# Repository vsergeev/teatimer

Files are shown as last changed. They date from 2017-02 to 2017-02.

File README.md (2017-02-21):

# teatimer

A simple kitchen timer implemented in digital logic on a Lattice MachXO2 CPLD.

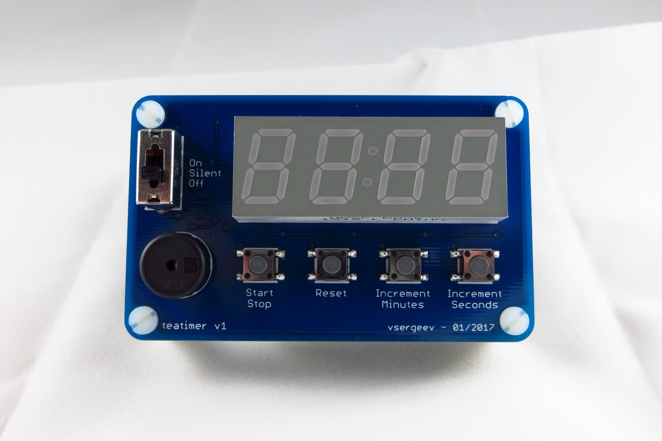
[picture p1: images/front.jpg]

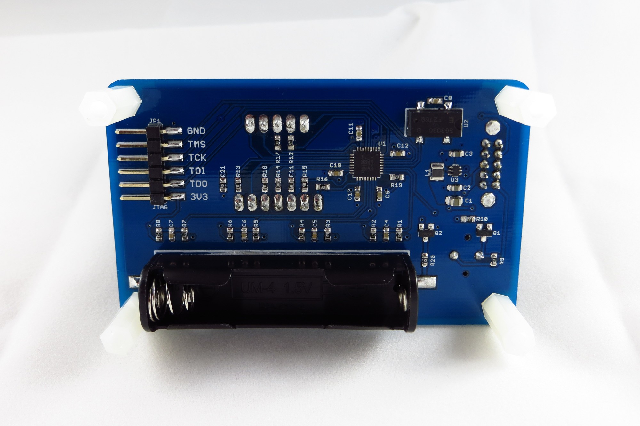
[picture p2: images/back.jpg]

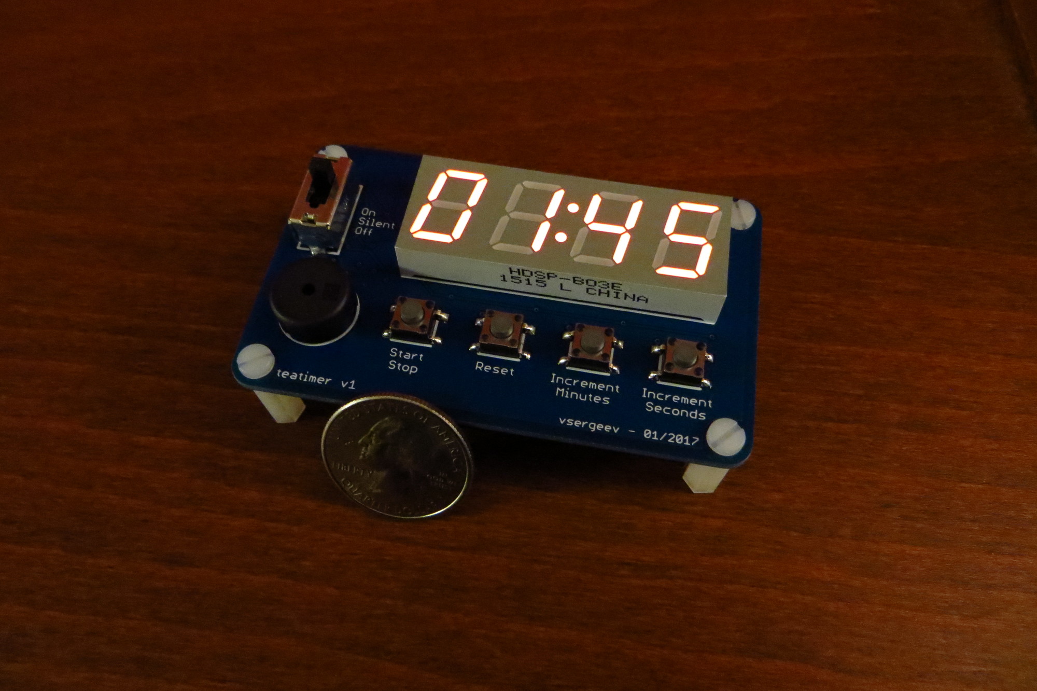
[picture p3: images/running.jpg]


(It's brighter in person.)

## Details

* Features
    * Large 7-segment display
    * Count-down/count-up timer
    * Alarm and silent modes
    * AAA battery powered
* Limitations
    * 10 hour battery life
* ICs
    * Lattice MachXO2-256 CPLD
    * SG-3030JC 32.768 kHz Oscillator
    * TLV61225 Boost Converter 1.5V -> 3.3V
* Dimensions of 80mm x 49mm
* Power consumption of ~100mA @ 1.5V (mostly from LEDs)

## Project Structure

* [`README.md`](README.md) - this README
* [`teatimer.v`](teatimer.v) - Verilog source
* [`teatimer_tb.v`](teatimer_tb.v) - Verilog test bench
* [`Makefile`](Makefile) - Makefile for simulation
* [`hw/`](hw/) - Schematic and layout
    * `teatimer.sch` - Eagle schematic
    * `teatimer.brd` - Eagle layout
    * [`teatimer-sch.png`](hw/teatimer-sch.png) - Schematic image
    * [`teatimer-brd.png`](hw/teatimer-brd.png) - Layout image
    * [`gerbers/`](hw/gerbers/) - Gerbers
* [`diamond/`](diamond/) - Lattice Diamond project
    * `teatimer.ldf` - Project file
    * `teatimer.v` - Symlinked Verilog source
    * [`teatimer.lpf`](diamond/teatimer.lpf) - Constraints
    * [`teatimer.jed`](diamond/teatimer.jed) - JEDEC bitstream
* [`misc/`](misc/) - Miscellaneous scripts

## Design Summary

The design uses 67 bits of state, 91% of the LUTs for logic, and all of the
I/O.

```
Number of registers:     67 out of   322 (21%)
   PFU registers:           63 out of   256 (25%)
   PIO registers:            4 out of    66 (6%)
Number of SLICEs:       117 out of   128 (91%)
   SLICEs as Logic/ROM:    117 out of   128 (91%)
   SLICEs as RAM:            0 out of    96 (0%)
   SLICEs as Carry:         27 out of   128 (21%)
Number of LUT4s:        232 out of   256 (91%)
   Number used as logic LUTs:        178
   Number used as distributed RAM:     0
   Number used as ripple logic:       54
   Number used as shift registers:     0
Number of PIO sites used: 18 + 4(JTAG) out of 22 (100%)
Number of block RAMs:  0 out of 0
Number of GSRs:  1 out of 1 (100%)
```

## Datasheets

* U1, Lattice MachXO2 CPLD, LCMXO2-256HC-4SG32C - [family datasheet](http://www.latticesemi.com/~/media/LatticeSemi/Documents/DataSheets/MachXO23/MachXO2FamilyDataSheet.pdf)
* U2, 32.768 kHz Oscillator, SG-3030JC32.7680KB:ROHS - [datasheet](https://support.epson.biz/td/api/doc_check.php?dl=brief_SG-3040JC)
* U3, Boost Converter, TLV61225DCKR - [datasheet](http://www.ti.com/lit/ds/symlink/tlv61225.pdf)
* DISP1, 7-segment Display, HDSP-B03E - [datasheet](https://docs.broadcom.com/docs/AV02-0568EN)
* SP1, 4kHz Buzzer, PKM13EPYH4000-A0 - [datasheet](http://search.murata.co.jp/Ceramy/image/img/w_hinm/S0040E.pdf)

## Schematic

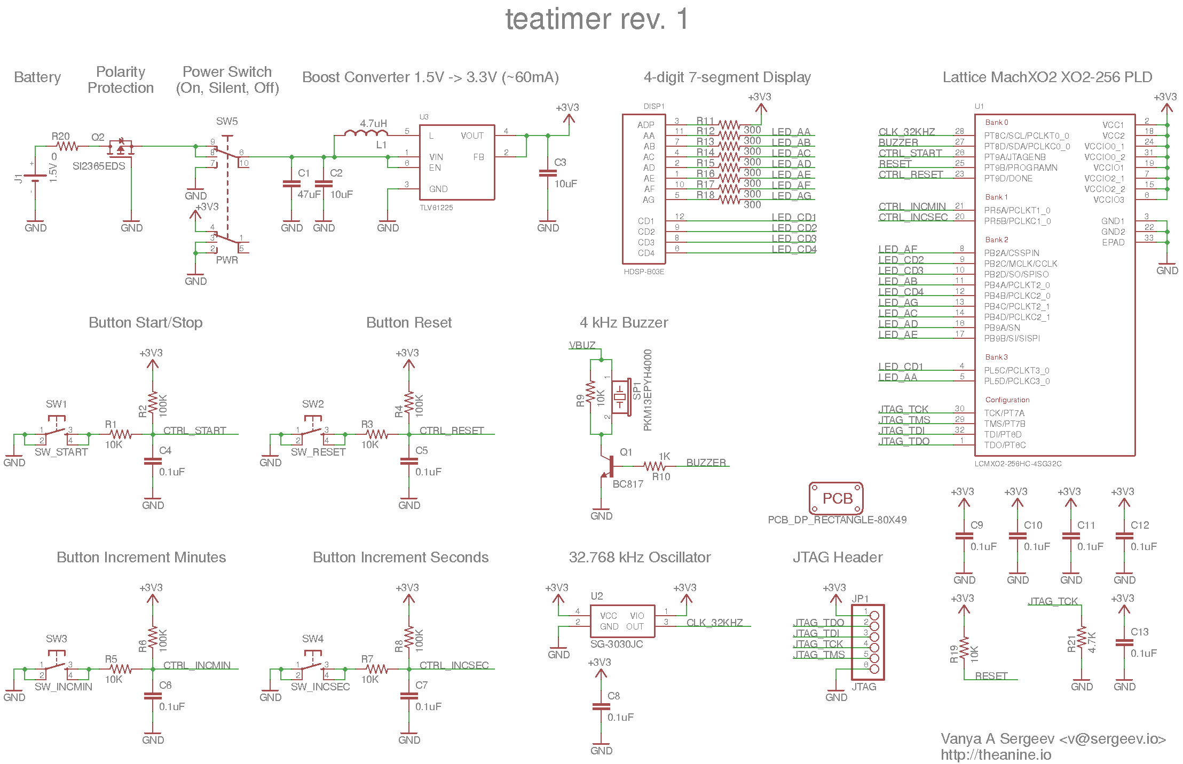
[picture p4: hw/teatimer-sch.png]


## Layout

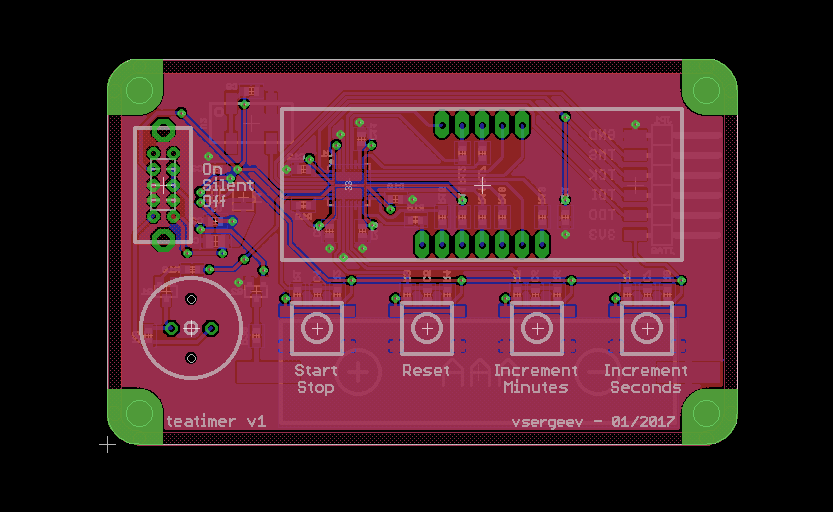
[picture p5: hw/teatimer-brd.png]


## Bill of Materials

| Qty | Part | Refdes | Digi-key Part Number | Total Price |
|:----|:---|:---|:---|:---|
| 1 | Lattice MachXO2-256 CPLD  | U1 | 220-2636-ND | 2.830 |
| 1 | Oscillator 32.768kHz | U2 | SG-3030JC32.7680KB:ROHS-ND | 1.398 |
| 1 | TLV61225 Boost Converter  | U3 | 296-36756-1-ND | 0.775 |
| 1 | NPN BJT (Buzzer Driver) | Q1 | BC817-40LT1GOSCT-ND | 0.103 |
| 1 | PMOS FET (Polarity Prot.) | Q2 | SI2365EDS-T1-GE3CT-ND | 0.297 |
| 4 | Tactile Switch (Buttons)  | SW1-SW4 | CKN9085CT-ND | 0.776 |
| 1 | Slide Switch (Power) | SW5 | CKN9558-ND | 0.648 |
| 1 | 7-segment LED Display | DISP1 | 516-2745-ND | 2.821 |
| 1 | Buzzer 4kHz | SP1 | 490-4698-ND | 0.499 |
| 1 | Battery Connector AAA | J1 | 36-2466-ND | 0.928 |
| 1 | SMD Header 1x6 | JP1 | 952-3235-ND | 0.711 |
| 1 | Inductor 4.7uH | L1 | 1276-6213-1-ND | 0.153 |
| 1 | Capacitor 47uF 0603 | C1 | 311-1897-1-ND | 0.322 |
| 2 | Capacitor 10uF 0603 | C2,C3 | 587-3258-1-ND | 0.238 |
| 10  | Capacitor 0.1uF 0603 | C4-C13 | 1276-1005-1-ND | 0.073 |
| 6 | Resistor 10K 0603 | R1,R3,R5,R7,R9,R19 | 311-10KGRCT-ND | 0.033 |
| 4 | Resistor 100K 0603 | R2,R4,R6,R8 | 311-100KGRCT-ND | 0.029 |
| 1 | Resistor 1K 0603 | R10 | 311-1.0KGRCT-ND | 0.010 |
| 1 | Resistor 4.7K 0603 | R21 | 311-4.7KGRCT-ND | 0.010 |
| 1 | Resistor 0.0 0603 | R20 | 311-0.0GRCT-ND | 0.010 |
| 8 | Resistor 300 0603 | R11-R18 | 311-300GRCT-ND | 0.044 |
| 4 | Standoffs M3 16mm Nylon | - | 952-2188-ND | 1.504 |
| 4 | Screws M3 Nylon | - | 36-29341-ND | 0.748 |
| 1 | PCB Lead-free, Shipped | - | - | 3.240 |
| | **Total per unit** | | | 18.20 |

Price breaks based on quantities to build 10 units. All prices in US dollars.

## Known Issues

* Silent mode is not 100% silent (design oversight)
* Limited battery life (~10 hours)

## Hardware Change Log

* v1 - 01/30/2017
    * Initial release

## RTL Change Log

* v0.1.0 - 01/30/2017
    * Initial release

## License

teatimer is [CC-BY-4.0](https://creativecommons.org/licenses/by/4.0/) licensed. See the included [LICENSE](LICENSE) file.

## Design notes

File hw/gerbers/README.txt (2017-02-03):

teatimer.cmp    - Top copper
teatimer.sol    - Bottom copper
teatimer.stc    - Top soldermask
teatimer.sts    - Bottom soldermask
teatimer.plc    - Top silkscreen
teatimer.pls    - Bottom silkscreen
teatimer.drd    - NC drill

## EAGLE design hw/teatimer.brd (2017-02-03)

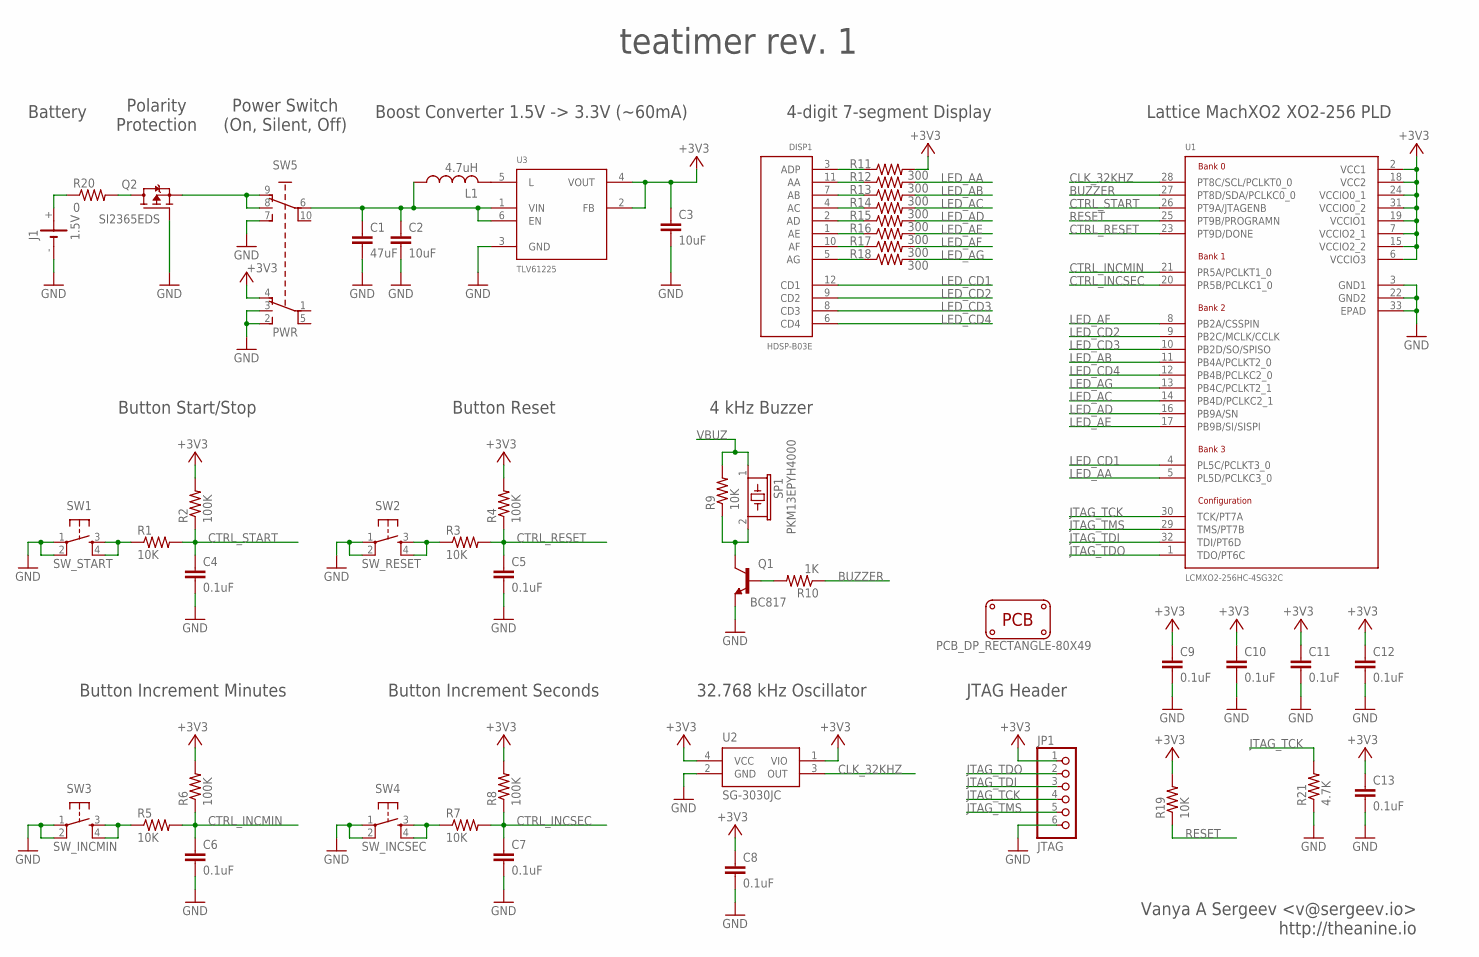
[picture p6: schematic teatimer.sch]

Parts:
C1: 47uF; C0805
C2, C3: 10uF; C0603
C4, C5, C6, C7, C8, C9, C10, C11, C12, C13: 0.1uF; C0603
DISP1: HDSP-B03E; HDSP-B0XE
J1: 1.5V; AAA-2466
JP1: JTAG; 1X06/90-SMD
L1: 4.7uH; L2520
PCB1: PCB_DP_RECTANGLE-80X49; DP8049_V1
Q1: BC817; SOT23-BEC
Q2: SI2365EDS; SOT23
R1, R3, R5, R7, R9, R19: 10K; R0603
R2, R4, R6, R8: 100K; R0603
R10: 1K; R0603
R11, R12, R13, R14, R15, R16, R17, R18: 300; R0603
R20: 0; R0603
R21: 4.7K; R0603
SP1: PKM13EPYH4000
SW1: SW_START; PTS645
SW2: SW_RESET; PTS645
SW3: SW_INCMIN; PTS645
SW4: SW_INCSEC; PTS645
SW5: PWR; OS203011MV9QN1
U1: LCMXO2-256HC-4SG32C; QFN32G-0.5-5X5MM
U2: SG-3030JC
U3: TLV61225; SC70-6L

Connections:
+3V3: C3.1, C8.1, C9.1, C10.1, C11.1, C12.1, C13.1, JP1.1, R2.2, R4.2, R6.2, R8.2, R11.2, R19.2, SW5.4 (B1), U1.2 (VCC1), U1.6 (VCCIO3), U1.7 (VCCIO2_1), U1.15 (VCCIO2_2), U1.18 (VCC2), U1.19 (VCCIO1), U1.24 (VCCIO0_1), U1.31 (VCCIO0_2), U2.1 (VIO), U2.4 (VCC), U3.2 (FB), U3.4 (VOUT)
BUZZER: R10.1, U1.27 (PT8D/SDA/PCLKC0_0)
CLK_32KHZ: U1.28 (PT8C/SCL/PCLKT0_0), U2.3 (OUT)
CTRL_INCMIN: C6.1, R5.2, R6.1, U1.21 (PR5A/PCLKT1_0)
CTRL_INCSEC: C7.1, R7.2, R8.1, U1.20 (PR5B/PCLKC1_0)
CTRL_RESET: C5.1, R3.2, R4.1, U1.23 (PT9D/DONE)
CTRL_START: C4.1, R1.2, R2.1, U1.26 (PT9A/JTAGENB)
GND: C1.2, C2.2, C3.2, C4.2, C5.2, C6.2, C7.2, C8.2, C9.2, C10.2, C11.2, C12.2, C13.2, J1.-, JP1.6, Q1.E, Q2.1 (G), R21.1, SW1.1, SW1.2 (P1), SW2.1, SW2.2 (P1), SW3.1, SW3.2 (P1), SW4.1, SW4.2 (P1), SW5.2 (B3), SW5.3 (B2), SW5.7 (A3), U1.3 (GND1), U1.22 (GND2), U1.33 (EPAD), U2.2 (GND), U3.3 (GND)
JTAG_TCK: JP1.4, R21.2, U1.30 (TCK/PT7A)
JTAG_TDI: JP1.3, U1.32 (TDI/PT6D)
JTAG_TDO: JP1.2, U1.1 (TDO/PT6C)
JTAG_TMS: JP1.5, U1.29 (TMS/PT7B)
LED_AA: R12.2, U1.5 (PL5D/PCLKC3_0)
LED_AB: R13.2, U1.11 (PB4A/PCLKT2_0)
LED_AC: R14.2, U1.14 (PB4D/PCLKC2_1)
LED_AD: R15.2, U1.16 (PB9A/SN)
LED_AE: R16.2, U1.17 (PB9B/SI/SISPI)
LED_AF: R17.2, U1.8 (PB2A/CSSPIN)
LED_AG: R18.2, U1.13 (PB4C/PCLKT2_1)
LED_CD1: DISP1.12 (CD1), U1.4 (PL5C/PCLKT3_0)
LED_CD2: DISP1.9 (CD2), U1.9 (PB2C/MCLK/CCLK)
LED_CD3: DISP1.8 (CD3), U1.10 (PB2D/SO/SPISO)
LED_CD4: DISP1.6 (CD4), U1.12 (PB4B/PCLKC2_0)
unnamed: Q2.2 (S), SW5.8 (A2), SW5.9 (A1)
unnamed: L1.2, U3.5 (L)
unnamed: R3.1, SW2.3 (S), SW2.4 (S1)
unnamed: R1.1, SW1.3 (S), SW1.4 (S1)
unnamed: R5.1, SW3.3 (S), SW3.4 (S1)
unnamed: R7.1, SW4.3 (S), SW4.4 (S1)
unnamed: Q1.C, R9.1, SP1.2
unnamed: Q1.B, R10.2
unnamed: DISP1.3 (ADP), R11.1
unnamed: DISP1.11 (AA), R12.1
unnamed: DISP1.7 (AB), R13.1
unnamed: DISP1.4 (AC), R14.1
unnamed: DISP1.2 (AD), R15.1
unnamed: DISP1.1 (AE), R16.1
unnamed: DISP1.10 (AF), R17.1
unnamed: DISP1.5 (AG), R18.1
unnamed: J1.+, R20.1
unnamed: Q2.3 (D), R20.2
RESET: R19.1, U1.25 (PT9B/PROGRAMN)
VBAT: C1.1, C2.1, L1.1, SW5.6 (P1), U3.1 (VIN), U3.6 (EN)
VBUZ: R9.2, SP1.1

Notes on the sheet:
Power Switch (On, Silent, Off)
Boost Converter 1.5V -> 3.3V (~60mA)
Button Start/Stop
Button Reset
Button Increment Minutes
Button Increment Seconds
32.768 kHz Oscillator
4 kHz Buzzer
4-digit 7-segment Display
Lattice MachXO2 XO2-256 PLD
JTAG Header
teatimer rev. 1
Vanya A Sergeev <v@sergeev.io> http://theanine.io
Polarity Protection
Battery

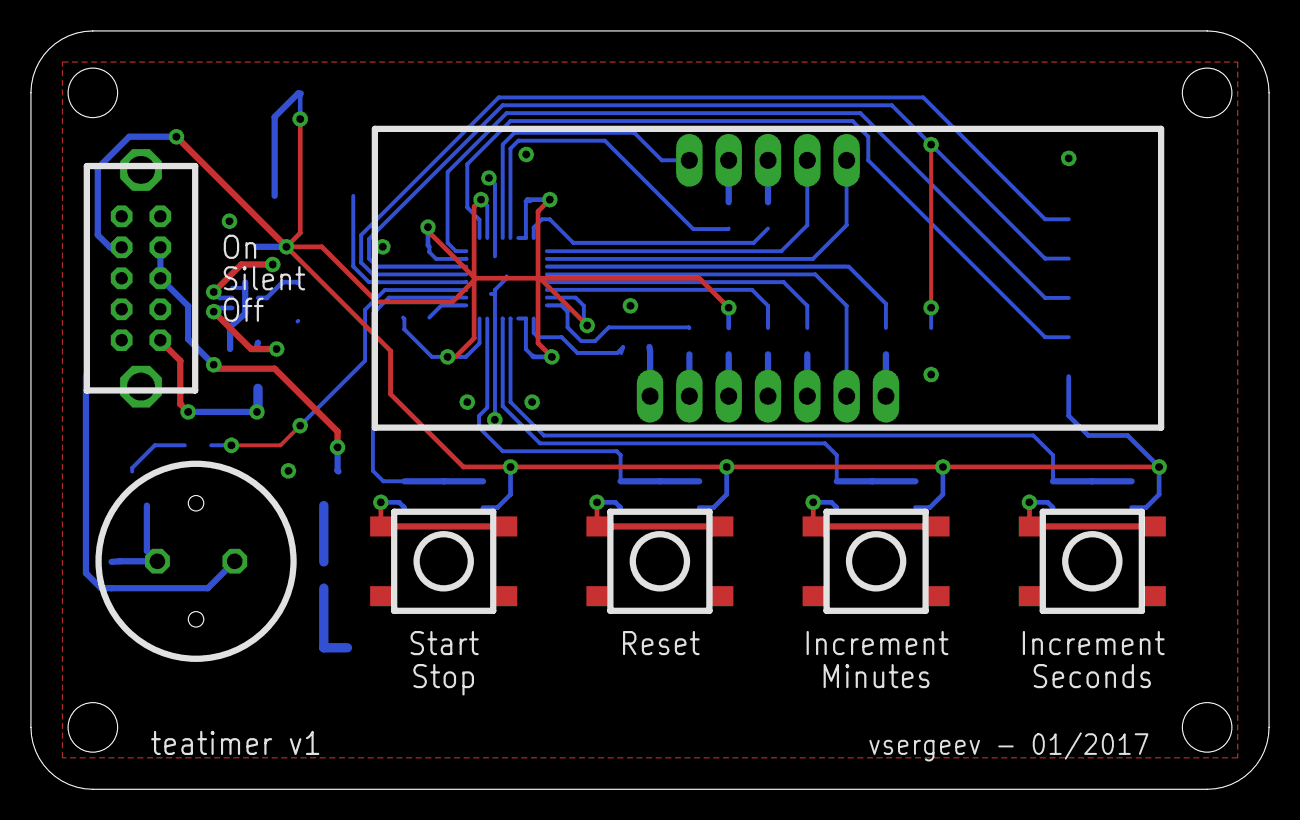
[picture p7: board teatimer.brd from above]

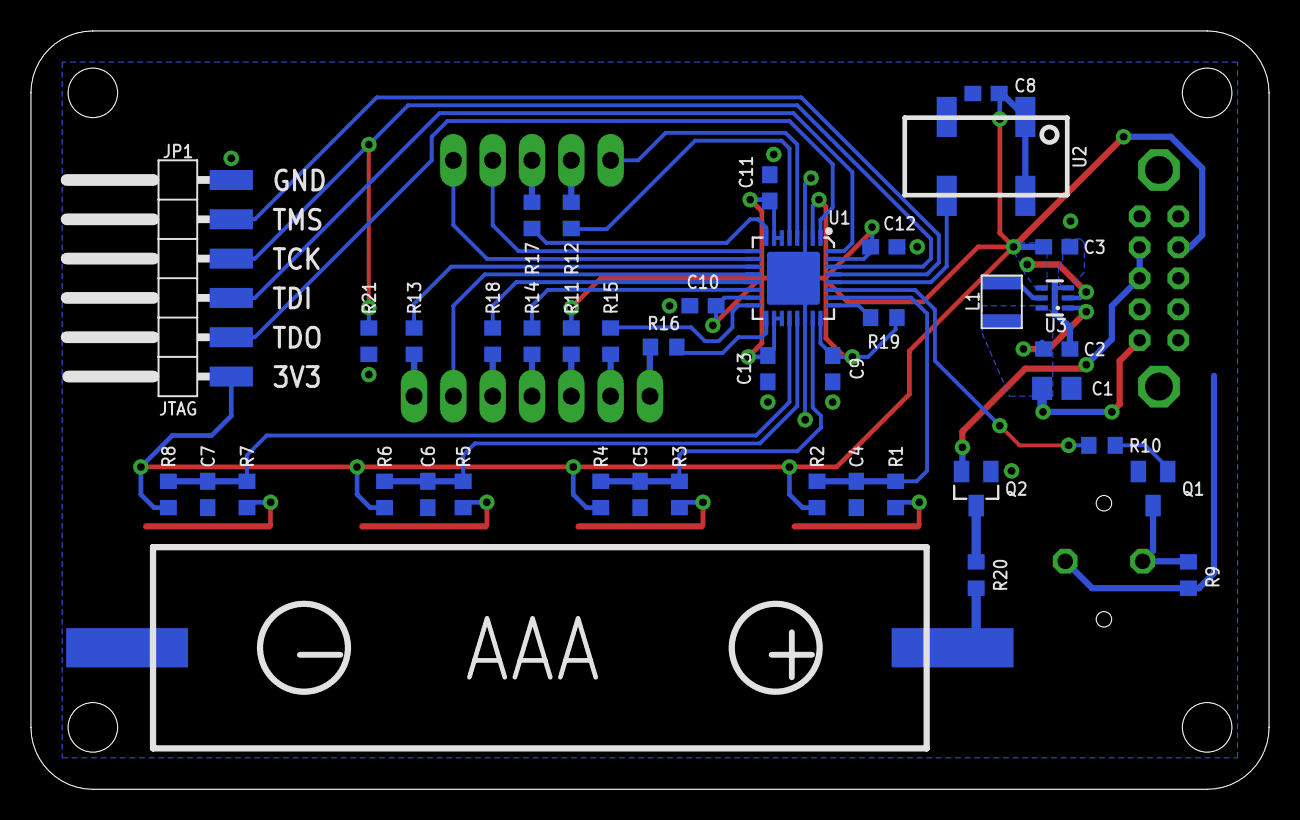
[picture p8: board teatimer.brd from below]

Board: 2 copper layers, 80.0 x 49.0 mm, 50 parts (42 on the bottom side), 44 nets.

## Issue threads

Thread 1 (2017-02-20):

Power Consumption

SergioBenitez, 2017-02-20:
Power consumption seems a bit high at ~100mA @ 1.5V. I'm curious: do you have a more detailed breakdown of the power consumption across components?

vsergeev, 2017-03-22:
It's like 75% due to LEDs and 25% due to loss by the boost converter. Unfortunately, to get the LEDs bright enough, they needed more current than initially projected and the boost converter is operating at relatively poor efficiency (75%).

Closed 2017-03-22.

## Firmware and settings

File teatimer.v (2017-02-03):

module clkdiv #(parameter divider=1) (input clk, input reset, output clkdiv);
    localparam COUNTER_SIZE = $clog2(divider);

    reg [COUNTER_SIZE-1:0] counter;

    assign clkdiv = counter[COUNTER_SIZE-1];

    always @(posedge clk or negedge reset) begin
        if (!reset) begin
            counter <= 0;
        end else begin
            counter <= counter + 1;
        end
    end
endmodule

module button_edge_to_pulse(input clk, input reset, input button_n, output button_pulse);
    reg button_sync;
    reg button_state;

    /* Button pulse on 1 -> 0 transition */
    assign button_pulse = !button_sync & button_state;

    always @(posedge clk or negedge reset) begin
        if (!reset) begin
            button_sync <= 0;
            button_state <= 0;
        end else begin
            button_sync <= button_n;
            button_state <= button_sync;
        end
    end
endmodule

module timer #(parameter divider=1024)
              (input clk_1khz,
               input reset,
               input ctrl_startstop,
               input ctrl_reset,
               input ctrl_incmin,
               input ctrl_incsec,
               output reg [6:0] time_min,
               output reg [5:0] time_sec,
               output reg alarm_enable);
    localparam COUNTER_SIZE = $clog2(divider);

    reg [2:0] state, n_state;
    reg [COUNTER_SIZE-1:0] counter, n_counter;

    reg [6:0] n_time_min;
    reg [5:0] n_time_sec;
    reg n_alarm_enable;

    localparam  STATE_IDLE_DOWN  = 3'd0,
                STATE_IDLE_UP    = 3'd1,
                STATE_COUNT_DOWN = 3'd2,
                STATE_COUNT_UP   = 3'd3,
                STATE_EXPIRED    = 3'd4;

    always @(*) begin
        n_state = state;
        n_time_min = time_min;
        n_time_sec = time_sec;
        n_counter = 0;
        n_alarm_enable = 0;

        case (state)
            STATE_IDLE_DOWN, STATE_IDLE_UP: begin
                if (ctrl_startstop) begin
                    n_counter = 1;
                    if ((time_sec == 0 && time_min == 0) || state == STATE_IDLE_UP) begin
                        n_state = STATE_COUNT_UP;
                    end else begin
                        n_state = STATE_COUNT_DOWN;
                    end
                end else if (ctrl_reset) begin
                    n_time_min = 0;
                    n_time_sec = 0;
                end else if (ctrl_incmin) begin
                    n_state = STATE_IDLE_DOWN;
                    if (time_min == 99) begin
                        /* Saturate at 99 minutes */
                    end else begin
                        n_time_min = time_min + 1;
                    end
                end else if (ctrl_incsec) begin
                    n_state = STATE_IDLE_DOWN;
                    if (time_min == 99 && time_sec >= 45) begin
                        /* Saturate at 99:59 time */
                        n_time_sec = 59;
                    end else if (time_sec >= 45) begin
                        n_time_min = time_min + 1;
                        n_time_sec = time_sec - 45;
                    end else begin
                        n_time_sec = time_sec + 15;
                    end
                end
            end
            STATE_COUNT_UP: begin
                if (ctrl_startstop) begin
                    n_state = STATE_IDLE_UP;
                end else if (counter == 0) begin
                    if (time_min == 99 && time_sec == 59) begin
                        /* Saturate at 99:59 time */
                    end else if (time_sec == 59) begin
                        n_time_min = time_min + 1;
                        n_time_sec = 0;
                    end else begin
                        n_time_sec = time_sec + 1;
                    end
                end
                n_counter = counter + 1;
            end
            STATE_COUNT_DOWN: begin
                if (ctrl_startstop) begin
                    n_state = STATE_IDLE_DOWN;
                end else if (counter == 0) begin
                    if (time_min == 0 && time_sec == 1) begin
                        n_time_sec = 0;
                        n_state = STATE_EXPIRED;
                        n_alarm_enable = 1;
                    end else if (time_sec == 0) begin
                        n_time_min = time_min - 1;
                        n_time_sec = 59;
                    end else begin
                        n_time_sec = time_sec - 1;
                    end
                end
                n_counter = counter + 1;
            end
            STATE_EXPIRED: begin
                if (ctrl_startstop || ctrl_reset) begin
                    n_state = STATE_IDLE_DOWN;
                end else begin
                    n_alarm_enable = 1;
                end
            end
        endcase
    end

    always @(posedge clk_1khz or negedge reset) begin
        if (!reset) begin
            state <= STATE_IDLE_DOWN;
            time_min <= 0;
            time_sec <= 0;
            counter <= 0;
            alarm_enable <= 0;
        end else begin
            state <= n_state;
            time_min <= n_time_min;
            time_sec <= n_time_sec;
            counter <= n_counter;
            alarm_enable <= n_alarm_enable;
        end
    end
endmodule

module add3(input [3:0] in, output reg [3:0] out);
    always @(in) begin
        case (in)
            4'b0000: out = 4'b0000;
            4'b0001: out = 4'b0001;
            4'b0010: out = 4'b0010;
            4'b0011: out = 4'b0011;
            4'b0100: out = 4'b0100;
            4'b0101: out = 4'b1000;
            4'b0110: out = 4'b1001;
            4'b0111: out = 4'b1010;
            4'b1000: out = 4'b1011;
            4'b1001: out = 4'b1100;
            default: out = 4'b0000;
        endcase
    end
endmodule

module bin_to_bcd(input [6:0] bin, output [7:0] bcd);
    /* 7-bit Double dabble */

    wire [3:0] c1, c2, c3, c4, c5, c6, c7;
    wire [3:0] d1, d2, d3, d4, d5, d6, d7;

    assign d1 = {2'b0, bin[6:5]};
    assign d2 = {c1[2:0], bin[4]};
    assign d3 = {c2[2:0], bin[3]};
    assign d4 = {c3[2:0], bin[2]};
    assign d5 = {c4[2:0], bin[1]};
    assign d6 = {1'b0, c1[3], c2[3], c3[3]};
    assign d7 = {c6[2:0], c4[3]};

    add3 m1(d1, c1);
    add3 m2(d2, c2);
    add3 m3(d3, c3);
    add3 m4(d4, c4);
    add3 m5(d5, c5);
    add3 m6(d6, c6);
    add3 m7(d7, c7);

    assign bcd = {c7[2:0], c5[3:0], bin[0]};
endmodule
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
